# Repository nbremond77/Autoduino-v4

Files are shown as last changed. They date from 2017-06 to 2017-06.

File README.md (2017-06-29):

# Autoduino

Arduino DUE shield to interface the I/O modules of A4 Technology // Autoduino est un bouclier pour Arduino DUE qui permet de piloter les maquettes A4 Technology utilisées pour l'enseignement de la technologie. Il permet également d'interfacer des module Grove.

La face "Bottom":
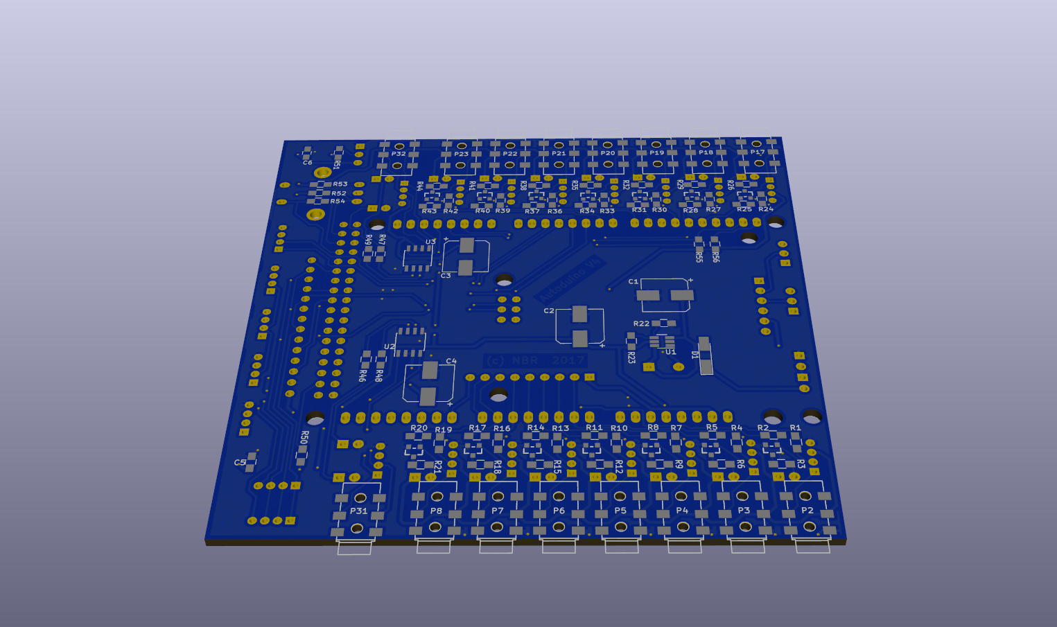
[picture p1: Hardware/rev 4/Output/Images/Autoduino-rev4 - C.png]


La face "Top"
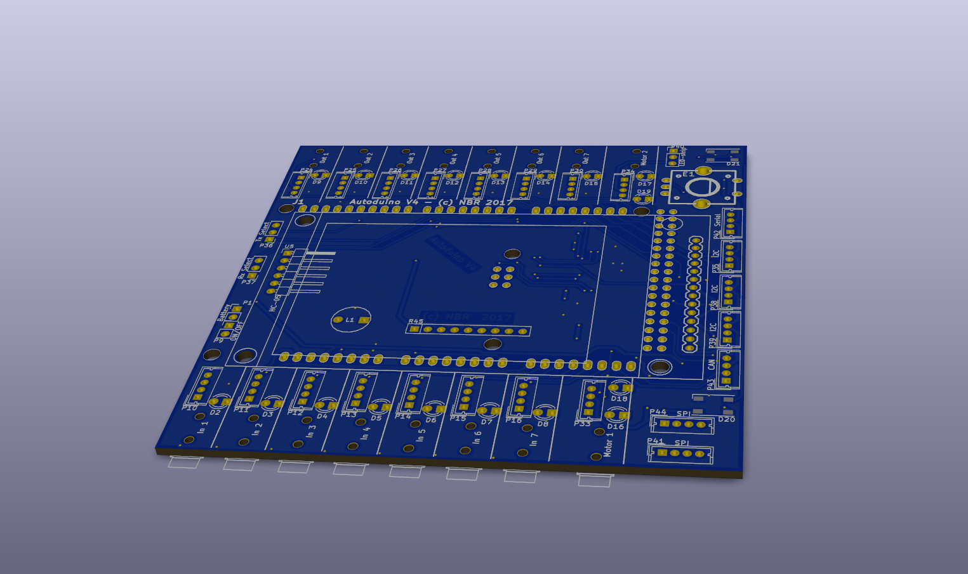
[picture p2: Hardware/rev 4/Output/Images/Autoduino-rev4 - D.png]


Exemples de maquettes A4:

http://www.a4.fr/maquette-motorisee-programmable-portail-1-battant-version-kit.html

http://www.a4.fr/banc-d-essai-eclairage-domestique-autolumi-version-kit.html

http://www.a4.fr/autoalarme-maquette-experimentale-d-un-systeme-d-alarme-kit.html

Vous trouverez sur ce site, les fichiers relatif à la carte électronique, et les développements logiciels associés, dès qu'ils seront disponibles. Cette carte peut être programmée en utilisant l'environnement Arduino. Mais elle peut également en programmée avec Blockly@rDuino, l'excellent projet de Sébastien Canet:

http://technologiescollege.github.io/Blockly-at-rduino/

https://github.com/technologiescollege/Blockly-at-rduino

# Introduction
Le bouclier Autoduino permet de piloter les maquettes A4 technology grâce à un Arduino DUE. Pour cela, le bouclier est équipé de 
- 14 connecteurs Jack 2.5mm permettant la connection des capteurs et actionneurs des maquette A4, équipé de LED pour indiquer l'état de l'entrée ou de la sortie. Des connecteurs Grove (4 broches) sont également prévus, et connectés aux mêmes entrées sorties (voir le schéma pour les détails). Les entrées sont équipées de résistances "Pull-Up" c'est à dire reliées à l'alimentation positive. Les entrées et sorties sont universelles (les schémas sont identiques), les 14 connections peuvent entre utilisées en entrée ou en sortie.
- 2 connecteurs jack 2.5mm pour deux moteurs DC, également complétés par des connecteurs Grove.
- 2 LED RGB adressables (type WS2812B),
- 1 encodeur/push,
- quelques connecteurs supplémentaires permettant de connecter des capteurs/actionneurs plus évolués (I2C, SPI, CAN, Serial...),
- 1 connecteur pour un module BlueTooth,
- 1 convertisseur Step/Up permettant d'alimenter la carte et l'Arduino avec deux piles de 1.5V, ou avec un accumulateur 3.7V,
- 1 connecteur pour un écran graphique couleur tactile de 2.8" connecté en SPI référencé TJCTM24028-SPI disponible pour un prix raisonnable sur Aliexpress.com.

Pour supporter le grand nombre d'entrées/sorties, il a été nécessaire d'utiliser un Arduino plus complet que le UNO. Nous avons choisi le Arduino DUE qui est équipé d'un processeur 32 bits permettant d'héberger des programmes trés complexes.

# Spécificités de l'Arduino DUE

L'Arduino DUE fonctionne en 3.3V, et n'est pas compatible avec des périphériques fonctionnant en 5V. Assurez vous que les périphériques utilisés fonctionnent bien en 3.3V. Les deux interface moteur prévues sur la carte Autoduino sont quant-à-elles alimentées en 5V.

# Schéma électronique

La conception du circuit imprimé a été réalisée avec kiCad, l'excellent logiciel de conception électronique, libre et multiplateforme. Le schéma est disponible ici:
https://github.com/nbremond77/Autoduino-v4/raw/master/Hardware/rev%204/Output/Autoduino-rev4.pdf

# Approvisionnement des composants

Les composants ont été achetés sur Aliepxress, et le PCb a été commandé chez PCBWay.com.

Voici des liens vers les principales références:

La carte Arduino DUE: https://fr.aliexpress.com/item/Free-shipping-Due-R3-ARM-Version-Main-Control-Board-with-usb-cable-for-arduino/32458422375.html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,searchweb201602_2_10152_10065_10151_10068_10305_10304_10306_10136_10137_10060_10302_10155_10062_437_10154_10056_5210020_10055_10054_10059_303_5290020_100031_10099_10103_10102_10096_10052_10053_10050_10107_10142_10051_5280011_10084_10083_10080_10082_10081_5260020_5270020_10177_5320020_10110_519_10111_10112_10113_10114_10182_10184_10078_10079_5240020_5230020_10073_10123_5250020_10189_142,searchweb201603_49,ppcSwitch_5&btsid=a1133e54-5694-44cb-906c-6a8b10082eb8&algo_expid=972c692f-a693-491d-9626-1f7036225856-1&algo_pvid=972c692f-a693-491d-9626-1f7036225856

Les connecteurs Jack 2.5mm CMS ref. PJ-242 : https://fr.aliexpress.com/item/500pcs-lot-PJ-242-6P-SMT-2-5MM-Female-Audio-Headphone-Jack-2-5MM-Dual-Track/32344264172.html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

L'écran LCD couleur tactile de 2.8" (attention, certains modèle ne sont pas équipés de l'interface tactile) : https://fr.aliexpress.com/item/2-8-Inch-240x320-Serial-Port-SPI-TFT-Screen-LCD-with-Touch-Screen-Panel-PCB-Board/32617643223.html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

Le module BlueTooth HC05 (les broches devront peut-être être déssoudées et remplacées par des barettes droites soudées sur la face inférieure) : https://fr.aliexpress.com/item/HC05-HC-05-master-slave-6pin-JY-MCU-anti-reverse-integrated-Bluetooth-serial-pass-through-module/32788718239.html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,searchweb201602_2_10152_10065_10151_10068_10305_10304_10306_10136_10137_10060_10302_10155_10062_437_10154_10056_5210020_10055_10054_10059_303_5290020_100031_10099_10103_10102_10096_10052_10053_10050_10107_10142_10051_5280011_10084_10083_10080_10082_10081_5260020_5270020_10177_5320020_10110_519_10111_10112_10113_10114_10182_10184_10078_10079_5240020_5230020_10073_10123_5250020_10189_142-10050,searchweb201603_49,ppcSwitch_5&btsid=7052be95-a9a1-4971-bb41-739faffda7ad&algo_expid=dd608b64-cccf-44a9-9c7e-1e9cdb78854b-7&algo_pvid=dd608b64-cccf-44a9-9c7e-1e9cdb78854b

Les autres composants sont des modèles standards.

# Circuit imprimé et fabrication

Autoduino utilise des composants CMS et des composants traversants. Le cuircuit imprimé fait 100x100mm et est du type double-face à trous métalisés. Nous l'avons fait fariqué chez PCBWay.com à un prix trés compétitif. Tous les fichiers nécessaires à sa fabrication sont dans le répertoire Output/Manufacturing (voir le fichier .Zip dans ce répertoire). Pensez également à commander un "Stencyl" pour la face "Bottom". Le Stencyl est un feuille de métal performée au laser au niveau des pastilles de soudure, et qui permet de grandement faciliter l'application de la pate à braser utilisée pour souder les  composants CMS.

Pour l'assemblage, de nombreux composants sont "montés en surface (CMS) sur la face "Bottom". Nous avons utilisé le Stencyl pour appliquer la pate à braser, positionné les composants CMS sur la carte, et passé la carte aisni équipé dans un four à refusion fait "maison" (plusieurs projets sont disponibles sur le web...).
Le montage des composants traversants, et des 2 LED sur la face "Top" se fait manuellement, aprés la refusion et le refroidissement de la carte. Cette méthode permet de réaliser plusieurs exemplaires de la carte en un temps raisonnable.

# Programmation
La programmation de l'Arduino peut se faire grâce à blockly@rDuino: http://technologiescollege.github.io/ en utilisant les blocs Grove par exemple.

http://technologiescollege.github.io/Blockly-at-rduino/

https://github.com/technologiescollege/Blockly-at-rduino

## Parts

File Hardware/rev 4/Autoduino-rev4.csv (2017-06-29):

Reference | Value | Footprint | Datasheet
U1 | MCP1640t-i/chy | TO_SOT_Packages_SMD:SOT-23-6_Handsoldering
C2 | 220uF/16V | Capacitors_SMD:CP_Elec_8x10
C1 | 220uF/16V | Capacitors_SMD:CP_Elec_8x10
R23 | 976k 1% | Resistors_SMD:R_0805_HandSoldering
R22 | 309k 1% | Resistors_SMD:R_0805_HandSoldering
L1 | 4.7uH | Inductors:INDUCTOR_V
E1 | Encoder_switch | BR_GoodLibraries:encoder_alps-ec12d
C6 | 100n | Capacitors_SMD:C_0805_HandSoldering
D20 | WS2812B | LEDs:LED_WS2812B-PLCC4
D21 | WS2812B | LEDs:LED_WS2812B-PLCC4
U5 | HC-05 | Pin_Headers:Pin_Header_Angled_1x06_Pitch2.54mm
C3 | 220uF/16V | Capacitors_SMD:CP_Elec_8x10
R51 | 220R | Resistors_SMD:R_0805_HandSoldering
P40 | LED-strip | Pin_Headers:Pin_Header_Straight_1x03_Pitch2.54mm
R46 | 470R | Resistors_SMD:R_0805_HandSoldering
R48 | 470R | Resistors_SMD:R_0805_HandSoldering
D16 | LED | LEDs:LED_D3.0mm
D18 | LED | LEDs:LED_D3.0mm
D2 | LED | LEDs:LED_D3.0mm
R3 | 470R | Resistors_SMD:R_0805_HandSoldering
Q1 | BSS138 | BR_GoodLibraries:SOT23_FET
R2 | 220R | Resistors_SMD:R_0805_HandSoldering
P10 | In_Out | Connectors_Molex:Molex_MicroLatch-53253-0470_04x2.00mm_Straight
R1 | 220R | Resistors_SMD:R_0805_HandSoldering
D3 | LED | LEDs:LED_D3.0mm
R6 | 470R | Resistors_SMD:R_0805_HandSoldering
Q2 | BSS138 | BR_GoodLibraries:SOT23_FET
R5 | 220R | Resistors_SMD:R_0805_HandSoldering
P11 | In_Out | Connectors_Molex:Molex_MicroLatch-53253-0470_04x2.00mm_Straight
R4 | 220R | Resistors_SMD:R_0805_HandSoldering
D4 | LED | LEDs:LED_D3.0mm
R9 | 470R | Resistors_SMD:R_0805_HandSoldering
Q3 | BSS138 | BR_GoodLibraries:SOT23_FET
R8 | 220R | Resistors_SMD:R_0805_HandSoldering
P12 | In_Out | Connectors_Molex:Molex_MicroLatch-53253-0470_04x2.00mm_Straight
R7 | 220R | Resistors_SMD:R_0805_HandSoldering
D5 | LED | LEDs:LED_D3.0mm
R12 | 470R | Resistors_SMD:R_0805_HandSoldering
Q4 | BSS138 | BR_GoodLibraries:SOT23_FET
R11 | 220R | Resistors_SMD:R_0805_HandSoldering
P13 | In_Out | Connectors_Molex:Molex_MicroLatch-53253-0470_04x2.00mm_Straight
R10 | 220R | Resistors_SMD:R_0805_HandSoldering
D6 | LED | LEDs:LED_D3.0mm
R15 | 470R | Resistors_SMD:R_0805_HandSoldering
Q5 | BSS138 | BR_GoodLibraries:SOT23_FET
R14 | 220R | Resistors_SMD:R_0805_HandSoldering
P14 | In_Out | Connectors_Molex:Molex_MicroLatch-53253-0470_04x2.00mm_Straight
R13 | 220R | Resistors_SMD:R_0805_HandSoldering
D9 | LED | LEDs:LED_D3.0mm
R26 | 470R | Resistors_SMD:R_0805_HandSoldering
Q8 | BSS138 | BR_GoodLibraries:SOT23_FET
R25 | 220R | Resistors_SMD:R_0805_HandSoldering
P24 | In_Out | Connectors_Molex:Molex_MicroLatch-53253-0470_04x2.00mm_Straight
R24 | 220R | Resistors_SMD:R_0805_HandSoldering
D10 | LED | LEDs:LED_D3.0mm
R29 | 470R | Resistors_SMD:R_0805_HandSoldering
Q9 | BSS138 | BR_GoodLibraries:SOT23_FET
R28 | 220R | Resistors_SMD:R_0805_HandSoldering
P25 | In_Out | Connectors_Molex:Molex_MicroLatch-53253-0470_04x2.00mm_Straight
R27 | 220R | Resistors_SMD:R_0805_HandSoldering
D11 | LED | LEDs:LED_D3.0mm
R32 | 470R | Resistors_SMD:R_0805_HandSoldering
Q10 | BSS138 | BR_GoodLibraries:SOT23_FET
R31 | 220R | Resistors_SMD:R_0805_HandSoldering
P26 | In_Out | Connectors_Molex:Molex_MicroLatch-53253-0470_04x2.00mm_Straight
R30 | 220R | Resistors_SMD:R_0805_HandSoldering
D12 | LED | LEDs:LED_D3.0mm
R35 | 470R | Resistors_SMD:R_0805_HandSoldering
Q11 | BSS138 | BR_GoodLibraries:SOT23_FET
R34 | 220R | Resistors_SMD:R_0805_HandSoldering
P27 | In_Out | Connectors_Molex:Molex_MicroLatch-53253-0470_04x2.00mm_Straight
R33 | 220R | Resistors_SMD:R_0805_HandSoldering
D13 | LED | LEDs:LED_D3.0mm
R38 | 470R | Resistors_SMD:R_0805_HandSoldering
Q12 | BSS138 | BR_GoodLibraries:SOT23_FET
R37 | 220R | Resistors_SMD:R_0805_HandSoldering
P28 | In_Out | Connectors_Molex:Molex_MicroLatch-53253-0470_04x2.00mm_Straight
R36 | 220R | Resistors_SMD:R_0805_HandSoldering
D7 | LED | LEDs:LED_D3.0mm
R18 | 470R | Resistors_SMD:R_0805_HandSoldering
Q6 | BSS138 | BR_GoodLibraries:SOT23_FET
R17 | 220R | Resistors_SMD:R_0805_HandSoldering
P15 | In_Out | Connectors_Molex:Molex_MicroLatch-53253-0470_04x2.00mm_Straight
R16 | 220R | Resistors_SMD:R_0805_HandSoldering
D14 | LED | LEDs:LED_D3.0mm
R41 | 470R | Resistors_SMD:R_0805_HandSoldering
Q13 | BSS138 | BR_GoodLibraries:SOT23_FET
R40 | 220R | Resistors_SMD:R_0805_HandSoldering
P29 | In_Out | Connectors_Molex:Molex_MicroLatch-53253-0470_04x2.00mm_Straight
R39 | 220R | Resistors_SMD:R_0805_HandSoldering
P33 | Motor 1 | Connectors_Molex:Molex_MicroLatch-53253-0470_04x2.00mm_Straight
U4 | ILI9341_LCD_Breakout_with_TS_IRQ | BR_GoodLibraries:LCD_2.8_Touch_screen
R45 | R-SIL 2K | Resistors_THT:R_Array_SIP9
R50 | 220R | Resistors_SMD:R_0805_HandSoldering
J1 | Arduino_Due_Header | BR_GoodLibraries:ARDUINO_MEGA_SHIELD
P1 | Battery | Pin_Headers:Pin_Header_Straight_1x02_Pitch2.54mm
U2 | L9110 | Housings_SOIC:SOIC-8_3.9x4.9mm_Pitch1.27mm
C4 | 220uF/16V | Capacitors_SMD:CP_Elec_8x10
R47 | 470R | Resistors_SMD:R_0805_HandSoldering
R49 | 470R | Resistors_SMD:R_0805_HandSoldering
D17 | LED | LEDs:LED_D3.0mm
D19 | LED | LEDs:LED_D3.0mm
P34 | Motor 2 | Connectors_Molex:Molex_MicroLatch-53253-0470_04x2.00mm_Straight
U3 | L9110 | Housings_SOIC:SOIC-8_3.9x4.9mm_Pitch1.27mm
P9 | ON/OFF Switch | Pin_Headers:Pin_Header_Straight_1x02_Pitch2.54mm
P36 | Tx Select | Pin_Headers:Pin_Header_Straight_1x03_Pitch2.54mm
P37 | Rx Select | Pin_Headers:Pin_Header_Straight_1x03_Pitch2.54mm
P31 | MOTOR1 | BR_GoodLibraries:3.5mm_stereo_jack_PJ242_NBR
P32 | MOTOR2 | BR_GoodLibraries:3.5mm_stereo_jack_PJ242_NBR
P7 | IN_OUT | BR_GoodLibraries:3.5mm_stereo_jack_PJ242_NBR
P6 | IN_OUT | BR_GoodLibraries:3.5mm_stereo_jack_PJ242_NBR
P5 | IN_OUT | BR_GoodLibraries:3.5mm_stereo_jack_PJ242_NBR
P4 | IN_OUT | BR_GoodLibraries:3.5mm_stereo_jack_PJ242_NBR
P3 | IN_OUT | BR_GoodLibraries:3.5mm_stereo_jack_PJ242_NBR
P2 | IN_OUT | BR_GoodLibraries:3.5mm_stereo_jack_PJ242_NBR
P17 | IN_OUT | BR_GoodLibraries:3.5mm_stereo_jack_PJ242_NBR
P18 | IN_OUT | BR_GoodLibraries:3.5mm_stereo_jack_PJ242_NBR
P19 | IN_OUT | BR_GoodLibraries:3.5mm_stereo_jack_PJ242_NBR
P20 | IN_OUT | BR_GoodLibraries:3.5mm_stereo_jack_PJ242_NBR
P21 | IN_OUT | BR_GoodLibraries:3.5mm_stereo_jack_PJ242_NBR
P22 | IN_OUT | BR_GoodLibraries:3.5mm_stereo_jack_PJ242_NBR
D8 | LED | LEDs:LED_D3.0mm
R21 | 470R | Resistors_SMD:R_0805_HandSoldering
Q7 | BSS138 | BR_GoodLibraries:SOT23_FET
R20 | 220R | Resistors_SMD:R_0805_HandSoldering
P16 | In_Out | Connectors_Molex:Molex_MicroLatch-53253-0470_04x2.00mm_Straight
R19 | 220R | Resistors_SMD:R_0805_HandSoldering
D15 | LED | LEDs:LED_D3.0mm
R44 | 470R | Resistors_SMD:R_0805_HandSoldering
Q14 | BSS138 | BR_GoodLibraries:SOT23_FET
R43 | 220R | Resistors_SMD:R_0805_HandSoldering
P30 | In_Out | Connectors_Molex:Molex_MicroLatch-53253-0470_04x2.00mm_Straight
R42 | 220R | Resistors_SMD:R_0805_HandSoldering
P8 | IN_OUT | BR_GoodLibraries:3.5mm_stereo_jack_PJ242_NBR
P23 | IN_OUT | BR_GoodLibraries:3.5mm_stereo_jack_PJ242_NBR
C5 | 100n | Capacitors_SMD:C_0805_HandSoldering
P35 | I2C | Connectors_Molex:Molex_MicroLatch-53253-0470_04x2.00mm_Straight
P38 | I2C | Connectors_Molex:Molex_MicroLatch-53253-0470_04x2.00mm_Straight
P39 | I2C | Connectors_Molex:Molex_MicroLatch-53253-0470_04x2.00mm_Straight
P41 | SPI | Connectors_Molex:Molex_MicroLatch-53253-0470_04x2.00mm_Straight
D1 | DIODE_SCHOTTKY | Diodes_SMD:D_MiniMELF_Handsoldering
P44 | SPI | Connectors_Molex:Molex_MicroLatch-53253-0470_04x2.00mm_Straight
P42 | Serial | Connectors_Molex:Molex_MicroLatch-53253-0470_04x2.00mm_Straight
R54 | 10k | Resistors_SMD:R_0805_HandSoldering
R53 | 10k | Resistors_SMD:R_0805_HandSoldering
R52 | 10k | Resistors_SMD:R_0805_HandSoldering
P43 | CAN | Connectors_Molex:Molex_MicroLatch-53253-0470_04x2.00mm_Straight
R55 | 10k | Resistors_SMD:R_0805_HandSoldering
R56 | 10k | Resistors_SMD:R_0805_HandSoldering

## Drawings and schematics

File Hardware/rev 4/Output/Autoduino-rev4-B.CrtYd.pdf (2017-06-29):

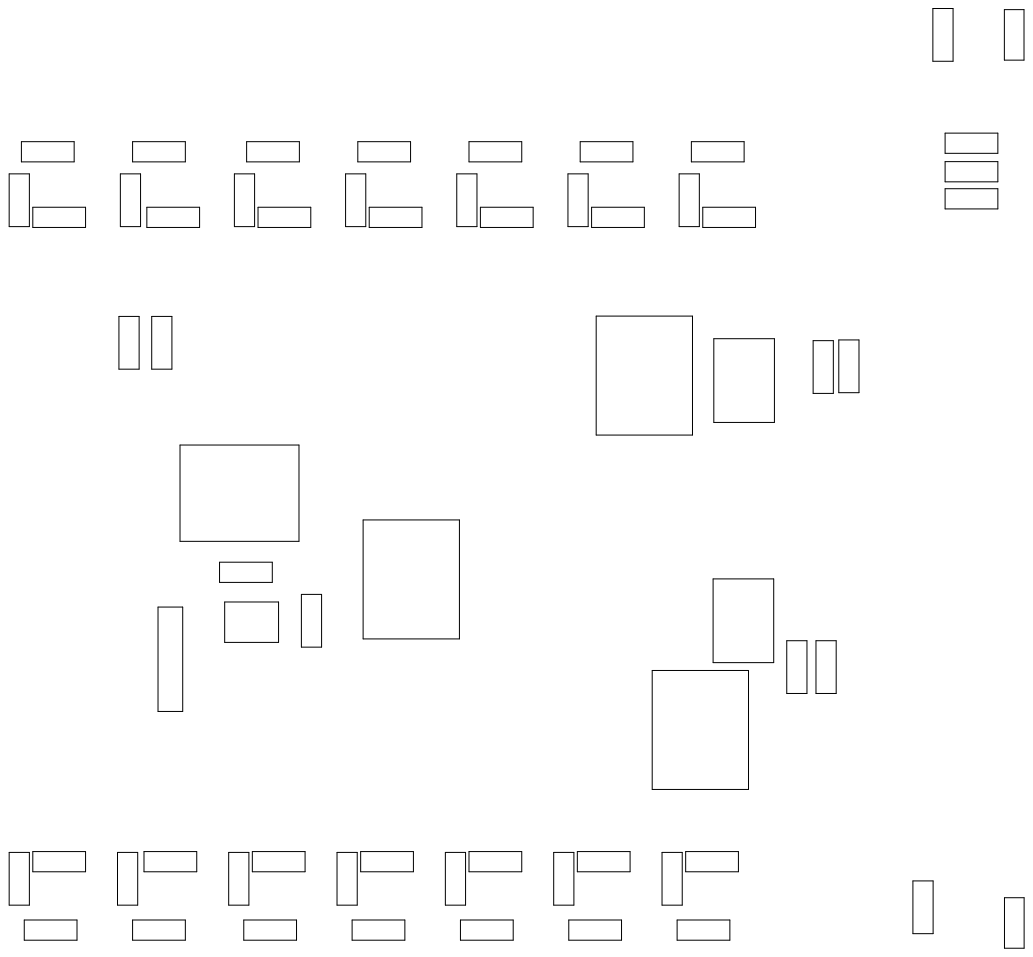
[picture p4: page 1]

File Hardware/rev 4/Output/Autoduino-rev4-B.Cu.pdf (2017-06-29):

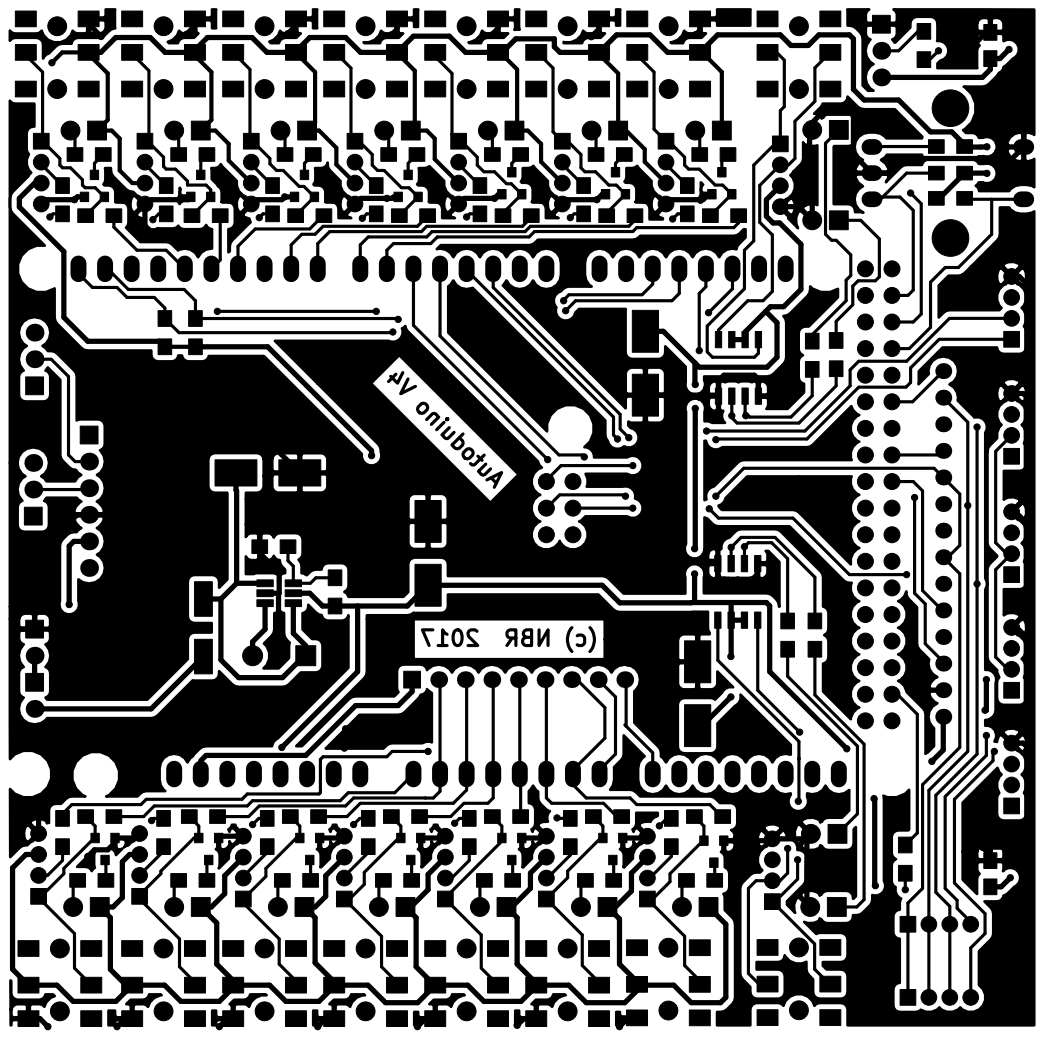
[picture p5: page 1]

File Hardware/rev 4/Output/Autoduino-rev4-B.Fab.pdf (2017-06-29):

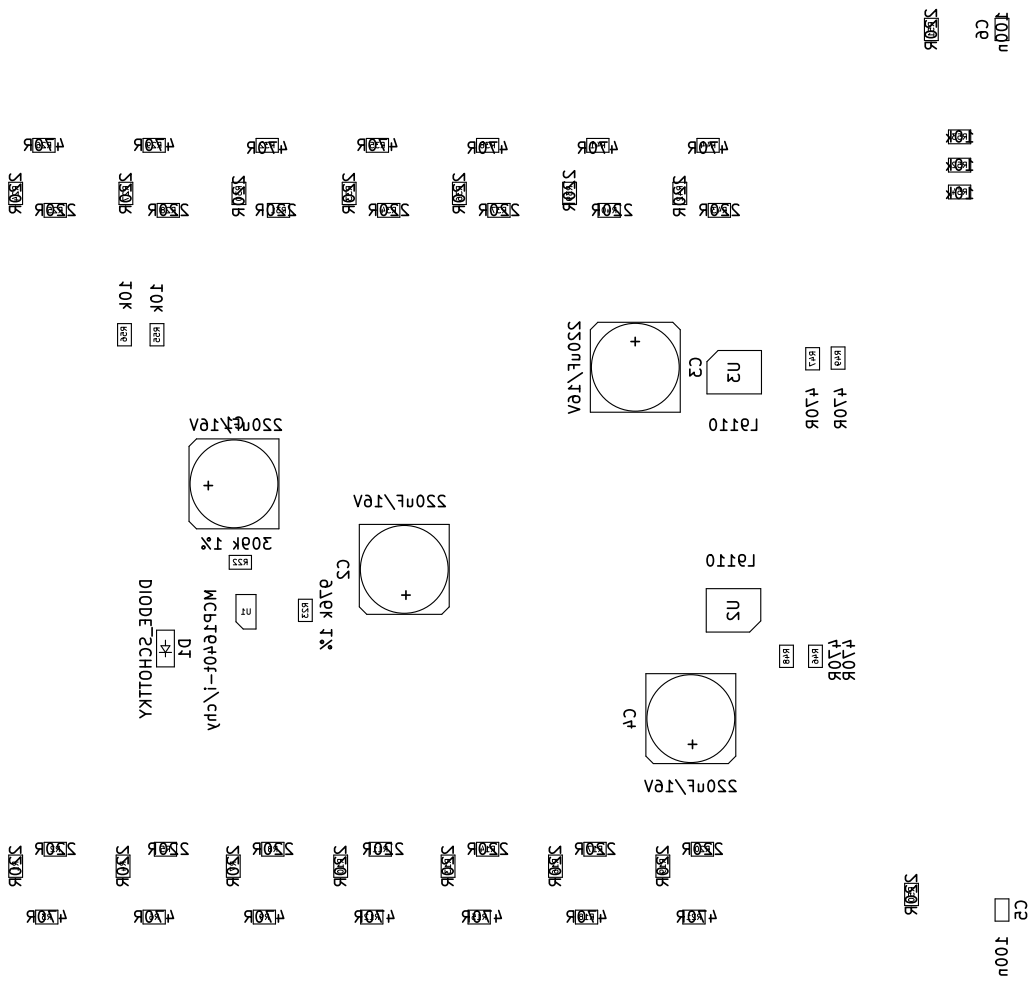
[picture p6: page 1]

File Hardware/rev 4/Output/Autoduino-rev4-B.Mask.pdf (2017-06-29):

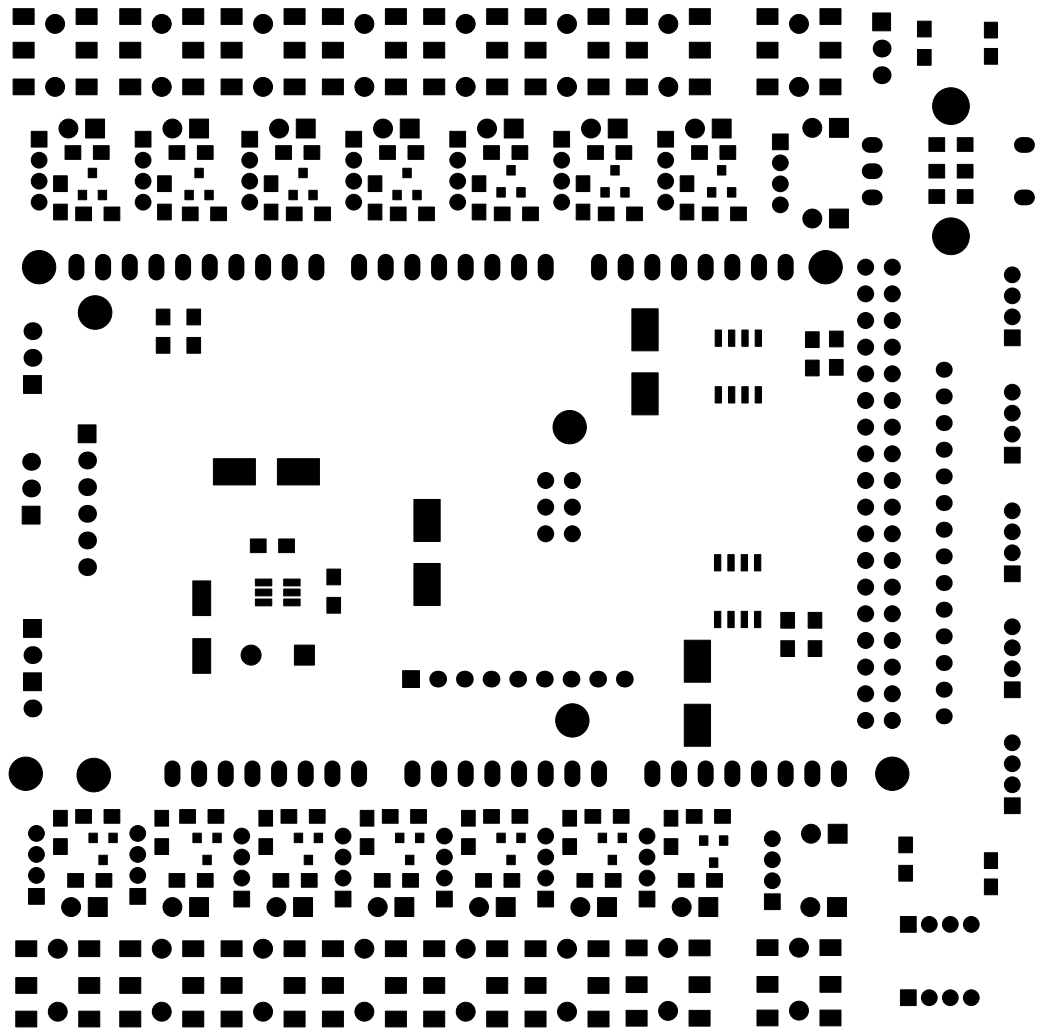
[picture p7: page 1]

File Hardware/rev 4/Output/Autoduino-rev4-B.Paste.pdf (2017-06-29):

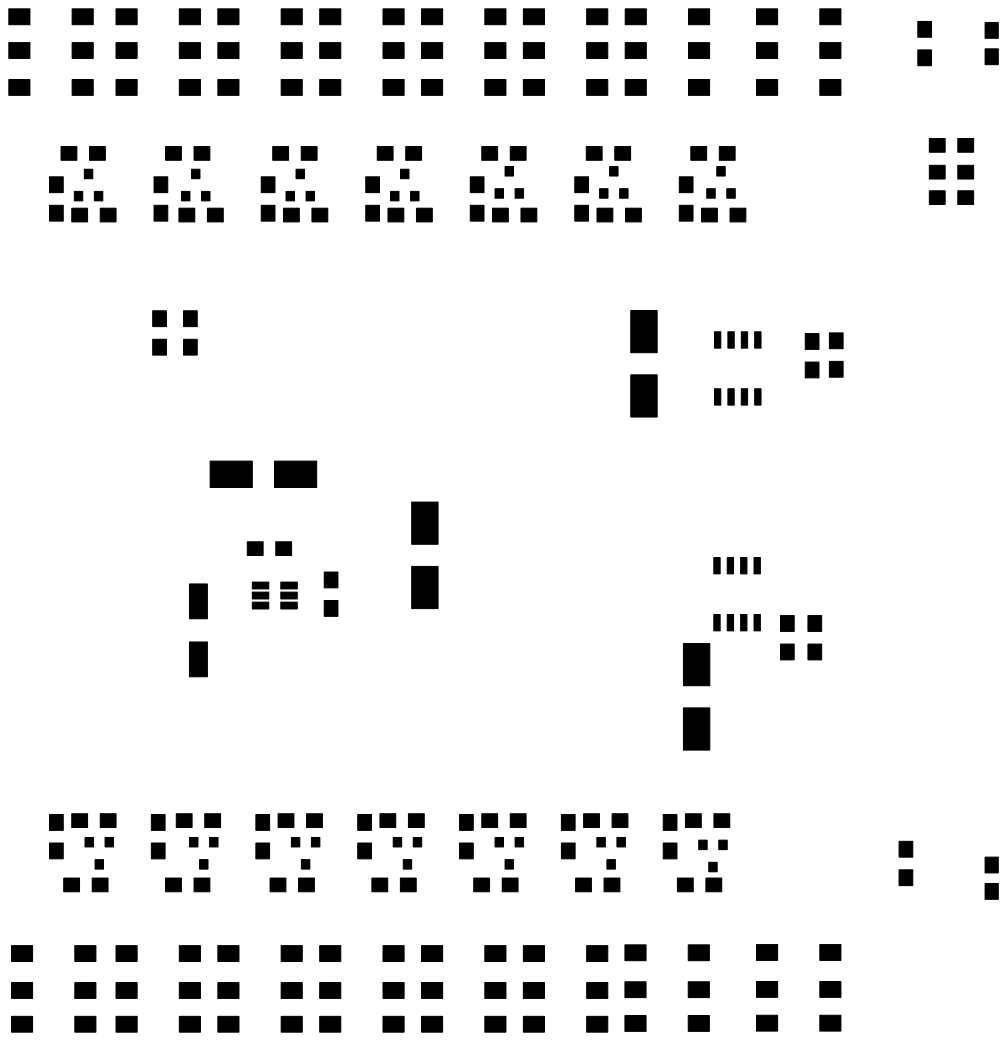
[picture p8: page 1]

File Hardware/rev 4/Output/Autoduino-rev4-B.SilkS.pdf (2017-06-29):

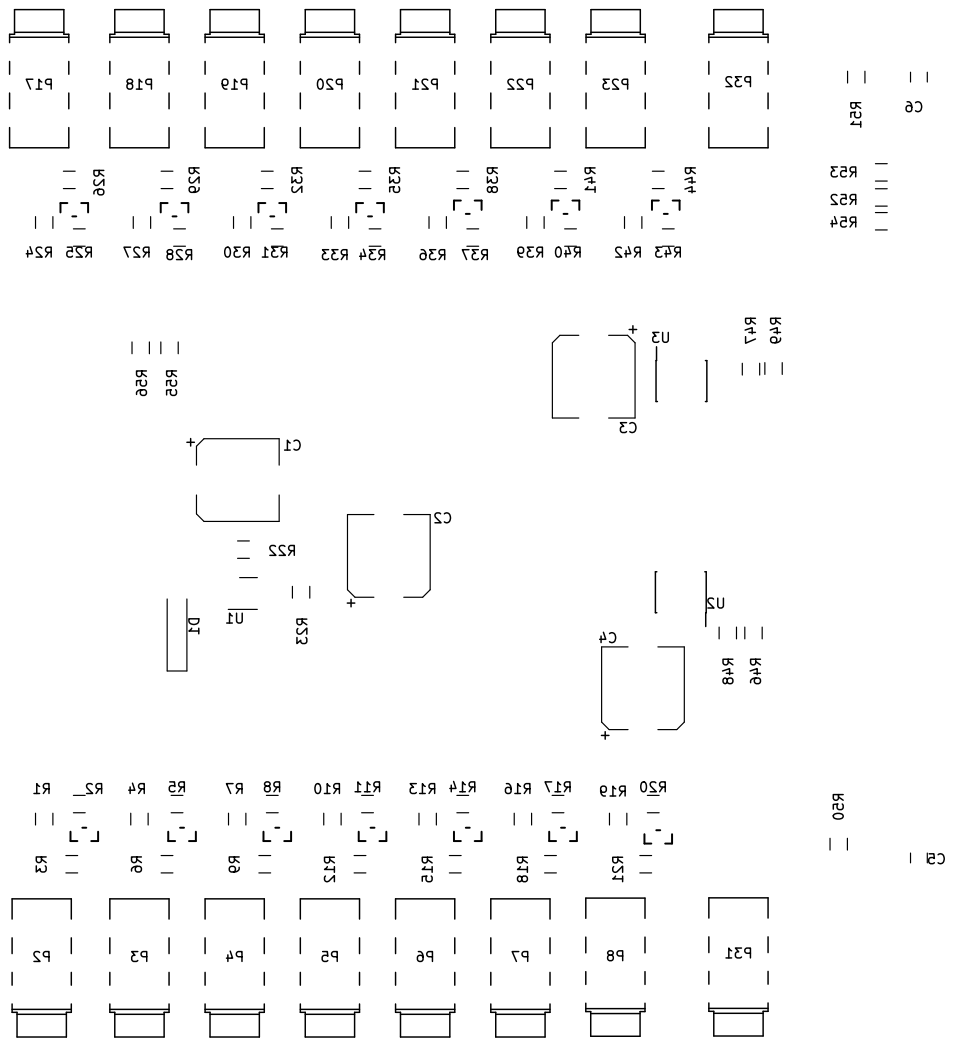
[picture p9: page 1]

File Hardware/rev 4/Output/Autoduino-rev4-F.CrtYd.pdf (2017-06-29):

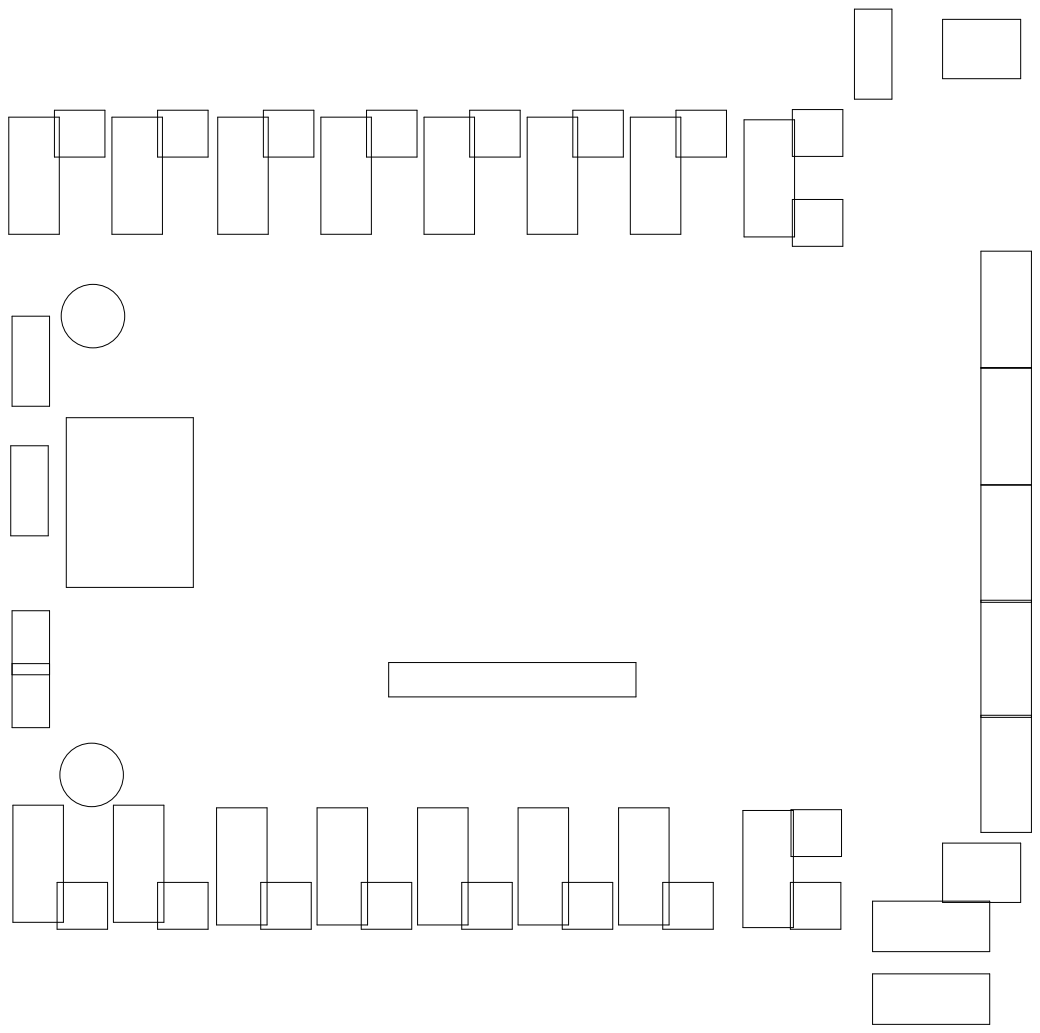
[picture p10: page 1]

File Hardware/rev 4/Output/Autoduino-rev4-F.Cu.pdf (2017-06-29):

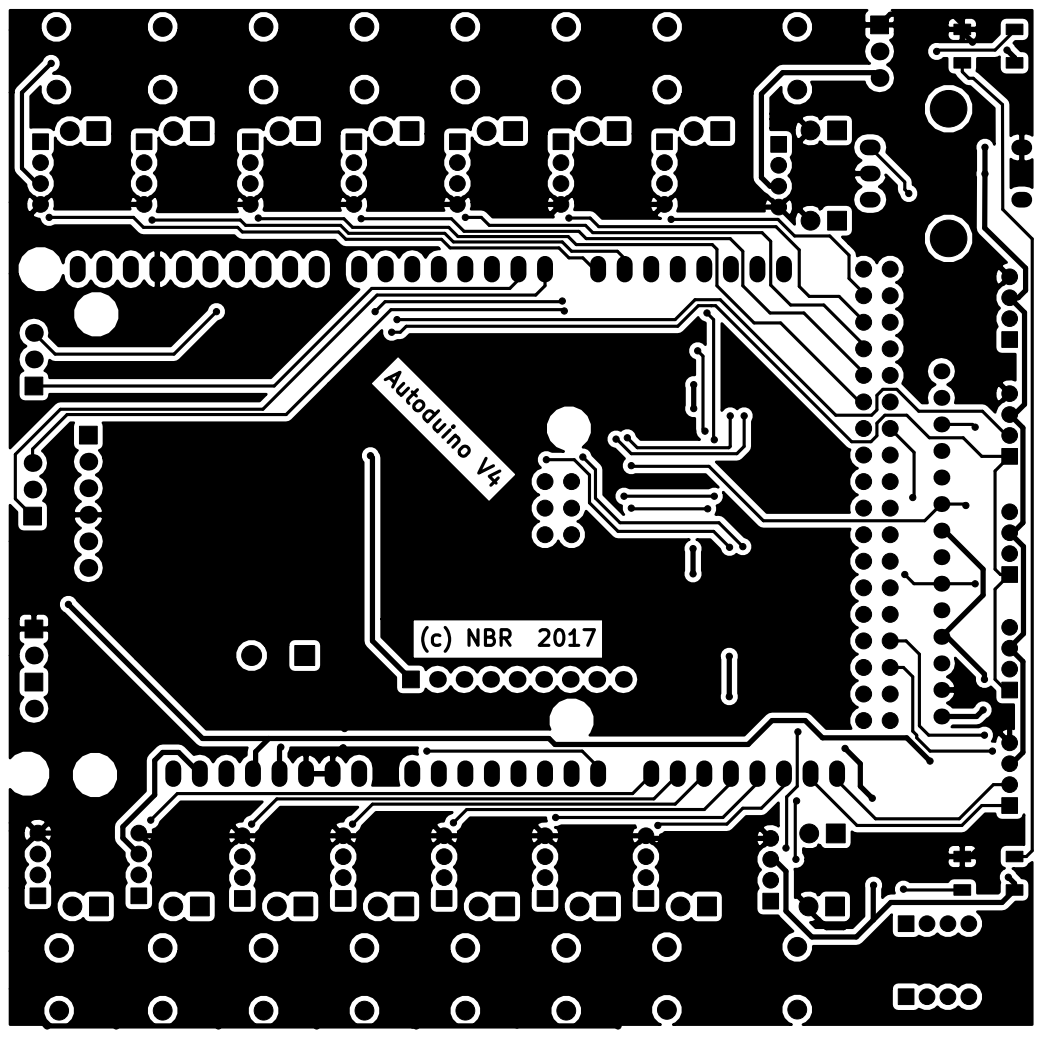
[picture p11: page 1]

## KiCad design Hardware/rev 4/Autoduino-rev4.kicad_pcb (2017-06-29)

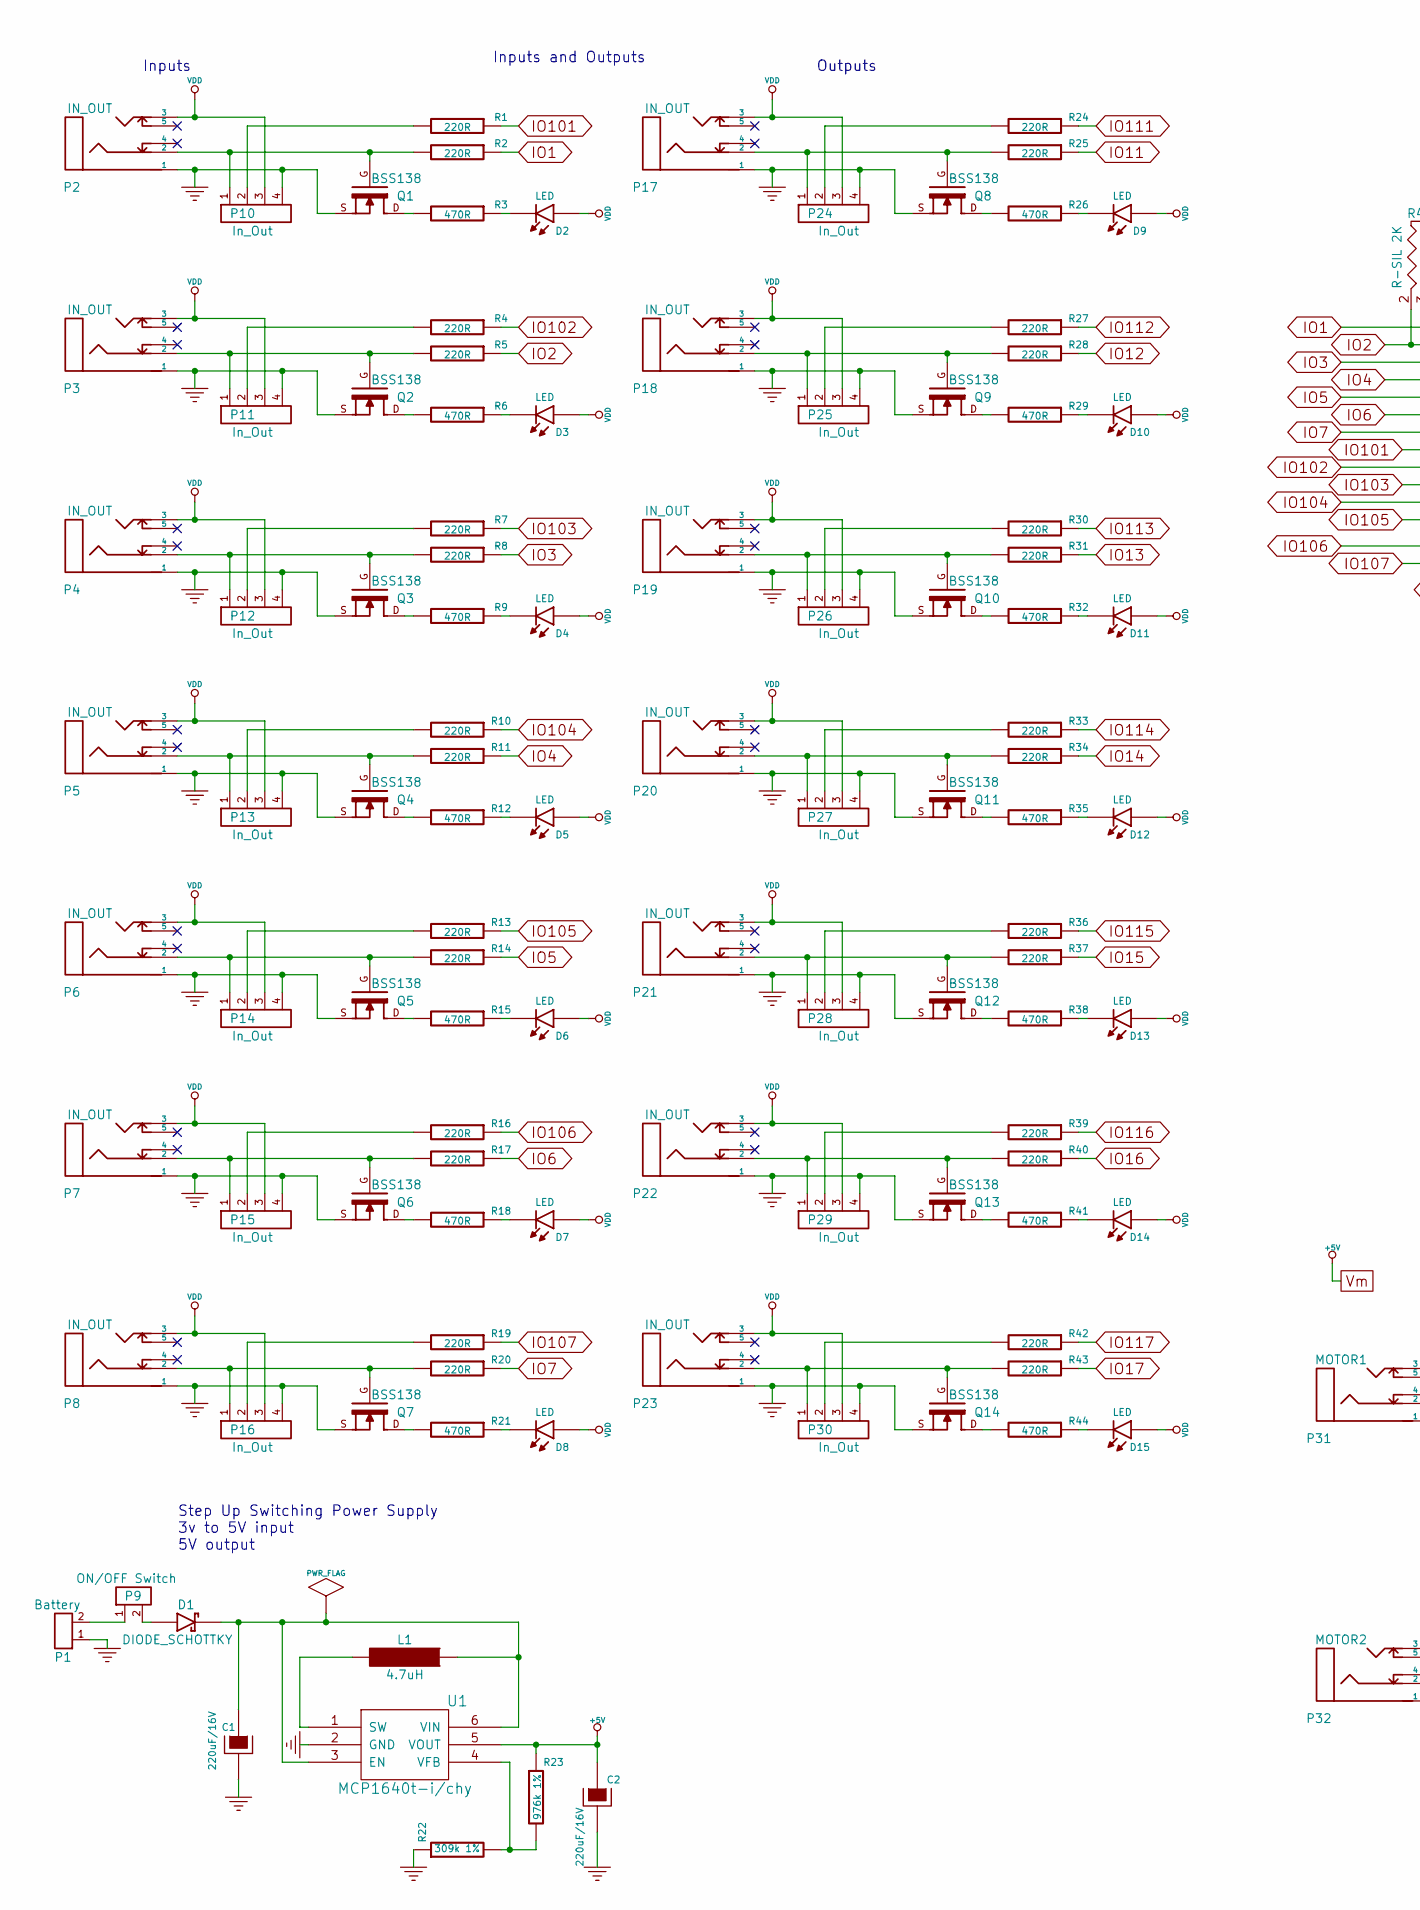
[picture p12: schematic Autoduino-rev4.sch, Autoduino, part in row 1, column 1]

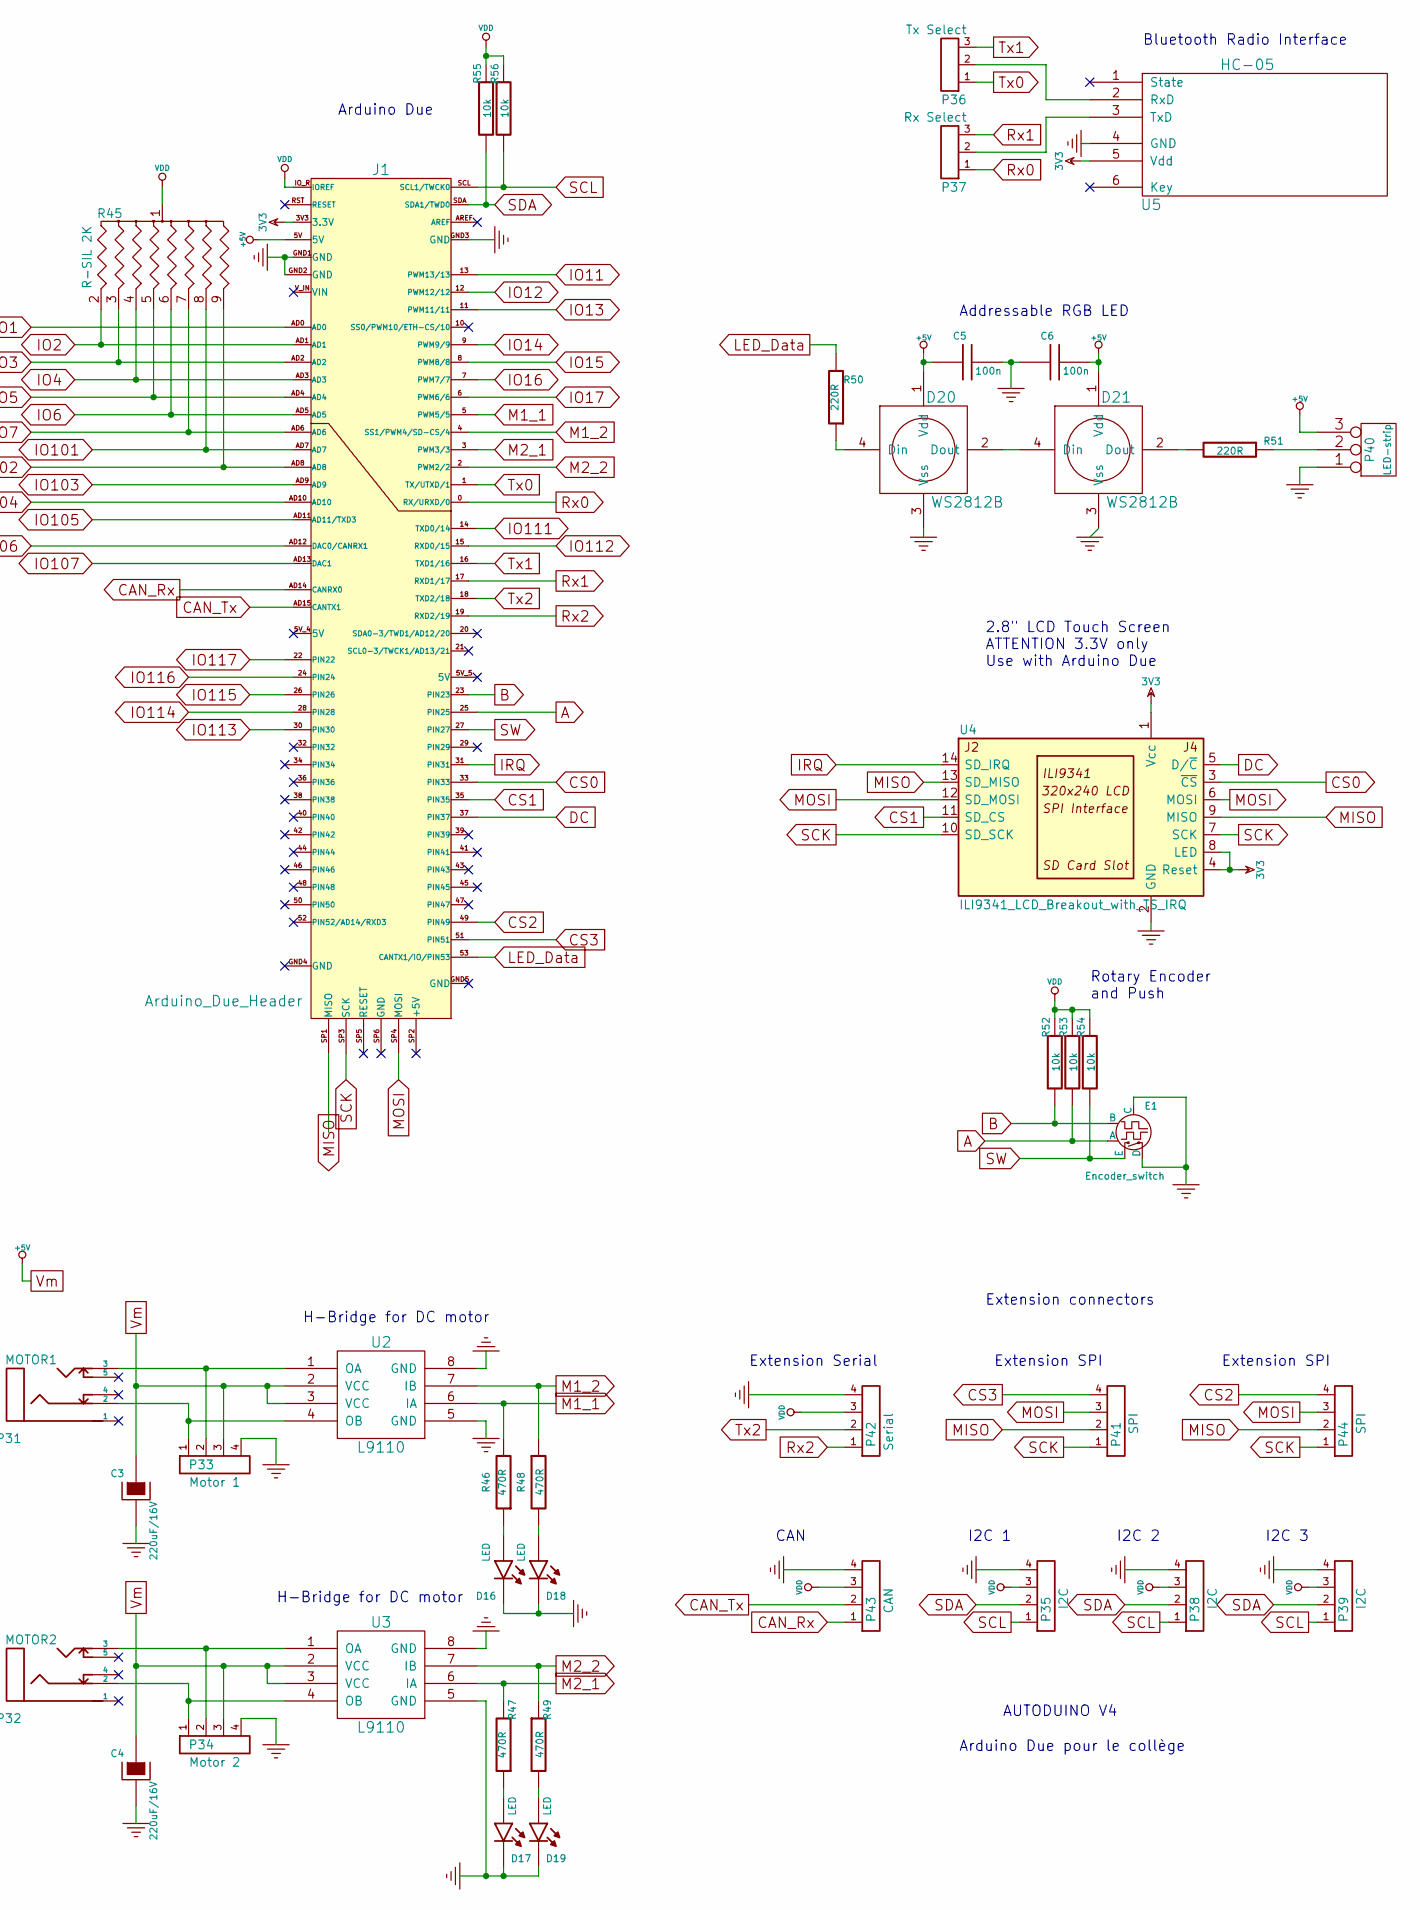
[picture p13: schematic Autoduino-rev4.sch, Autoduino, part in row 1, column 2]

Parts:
C1, C2, C3, C4: 220uF/16V; CP_Elec_8x10
C5, C6: 100n; C_0805_HandSoldering
D1: DIODE_SCHOTTKY; D_MiniMELF_Handsoldering
D2, D3, D4, D5, D6, D7, D8, D9, D10, D11, D12, D13, D14, D15, D16, D17, D18, D19: LED; LED_D3.0mm
D20, D21: WS2812B; LED_WS2812B-PLCC4
E1: Encoder_switch; encoder_alps-ec12d
J1: Arduino_Due_Header; ARDUINO_MEGA_SHIELD
L1: 4.7uH; INDUCTOR_V
P1: Battery; Pin_Header_Straight_1x02_Pitch2.54mm
P2, P3, P4, P5, P6, P7, P8, P17, P18, P19, P20, P21, P22, P23: IN_OUT; 3.5mm_stereo_jack_PJ242_NBR
P9: ON/OFF Switch; Pin_Header_Straight_1x02_Pitch2.54mm
P10, P11, P12, P13, P14, P15, P16, P24, P25, P26, P27, P28, P29, P30: In_Out; Molex_MicroLatch-53253-0470_04x2.00mm_Straight
P31: MOTOR1; 3.5mm_stereo_jack_PJ242_NBR
P32: MOTOR2; 3.5mm_stereo_jack_PJ242_NBR
P33: Motor 1; Molex_MicroLatch-53253-0470_04x2.00mm_Straight
P34: Motor 2; Molex_MicroLatch-53253-0470_04x2.00mm_Straight
P35, P38, P39: I2C; Molex_MicroLatch-53253-0470_04x2.00mm_Straight
P36: Tx Select; Pin_Header_Straight_1x03_Pitch2.54mm
P37: Rx Select; Pin_Header_Straight_1x03_Pitch2.54mm
P40: LED-strip; Pin_Header_Straight_1x03_Pitch2.54mm
P41, P44: SPI; Molex_MicroLatch-53253-0470_04x2.00mm_Straight
P42: Serial; Molex_MicroLatch-53253-0470_04x2.00mm_Straight
P43: CAN; Molex_MicroLatch-53253-0470_04x2.00mm_Straight
Q1, Q2, Q3, Q4, Q5, Q6, Q7, Q8, Q9, Q10, Q11, Q12, Q13, Q14: BSS138; SOT23_FET
R1, R2, R4, R5, R7, R8, R10, R11, R13, R14, R16, R17, R19, R20, R24, R25, R27, R28, R30, R31, R33, R34, R36, R37, R39, R40, R42, R43, R50, R51: 220R; R_0805_HandSoldering
R3, R6, R9, R12, R15, R18, R21, R26, R29, R32, R35, R38, R41, R44, R46, R47, R48, R49: 470R; R_0805_HandSoldering
R22: 309k 1%; R_0805_HandSoldering
R23: 976k 1%; R_0805_HandSoldering
R45: R-SIL 2K; R_Array_SIP9
R52, R53, R54, R55, R56: 10k; R_0805_HandSoldering
U1: MCP1640t-i/chy; SOT-23-6_Handsoldering
U2, U3: L9110; SOIC-8_3.9x4.9mm_Pitch1.27mm
U4: ILI9341_LCD_Breakout_with_TS_IRQ; LCD_2.8_Touch_screen
U5: HC-05; Pin_Header_Angled_1x06_Pitch2.54mm

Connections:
3V3: J1.3V3 (3.3V), U4.1 (Vcc), U4.4 (Reset), U4.8 (LED), U5.5 (Vdd)
A: E1.1 (A), J1.25 (PIN25), R53.2
B: E1.3 (B), J1.23 (PIN23), R52.2
CAN_Rx: J1.AD14 (CANRX0), P43.1
CAN_Tx: J1.AD15 (CANTX1), P43.2
CS0: J1.33 (PIN33), U4.3 (~CS)
CS1: J1.35 (PIN35), U4.11 (SD_CS)
CS2: J1.49 (PIN49), P44.4
CS3: J1.51 (PIN51), P41.4
DC: J1.37 (PIN37), U4.5 (D/~C)
GND: C1.2, C2.2, C3.2, C4.2, C5.2, C6.1, D16.2 (K), D17.2 (K), D18.2 (K), D19.2 (K), D20.3 (Vss), D21.3 (Vss), E1.2 (C), E1.5 (D), J1.GND1 (GND), J1.GND2 (GND), J1.GND3 (GND), P1.1, P2.1, P3.1, P4.1, P5.1, P6.1, P7.1, P8.1, P10.4, P11.4, P12.4, P13.4, P14.4, P15.4, P16.4, P17.1, P18.1, P19.1, P20.1, P21.1, P22.1, P23.1, P24.4, P25.4, P26.4, P27.4, P28.4, P29.4, P30.4, P33.4, P34.4, P35.4, P38.4, P39.4, P40.1, P42.4, P43.4, Q1.S, Q2.S, Q3.S, Q4.S, Q5.S, Q6.S, Q7.S, Q8.S, Q9.S, Q10.S, Q11.S, Q12.S, Q13.S, Q14.S, R22.1, U1.2 (GND), U2.5 (GND), U2.8 (GND), U3.5 (GND), U3.8 (GND), U4.2 (GND), U5.4 (GND)
IO1: J1.AD0, R2.1
IO2: J1.AD1, R5.1, R45.2
IO3: J1.AD2, R8.1, R45.3
IO4: J1.AD3, R11.1, R45.4
IO5: J1.AD4, R14.1, R45.5
IO6: J1.AD5, R17.1, R45.6
IO7: J1.AD6, R20.1, R45.7
IO11: J1.13 (PWM13/13), R25.1
IO12: J1.12 (PWM12/12), R28.1
IO13: J1.11 (PWM11/11), R31.1
IO14: J1.9 (PWM9/9), R34.1
IO15: J1.8 (PWM8/8), R37.1
IO16: J1.7 (PWM7/7), R40.1
IO17: J1.6 (PWM6/6), R43.1
IO101: J1.AD7, R1.1, R45.8
IO102: J1.AD8, R4.1, R45.9
IO103: J1.AD9, R7.1
IO104: J1.AD10, R10.1
IO105: J1.AD11 (AD11/TXD3), R13.1
IO106: J1.AD12 (DAC0/CANRX1), R16.1
IO107: J1.AD13 (DAC1), R19.1
IO111: J1.14 (TXD0/14), R24.1
IO112: J1.15 (RXD0/15), R27.1
IO113: J1.30 (PIN30), R30.1
IO114: J1.28 (PIN28), R33.1
IO115: J1.26 (PIN26), R36.1
IO116: J1.24 (PIN24), R39.1
IO117: J1.22 (PIN22), R42.1
IRQ: J1.31 (PIN31), U4.14 (SD_IRQ)
LED_Data: J1.53 (CANTX1/IO/PIN53), R50.2
M1_1: J1.5 (PWM5/5), R46.2, U2.6 (IA)
M1_2: J1.4 (SS1/PWM4/SD-CS/4), R48.1, U2.7 (IB)
M2_1: J1.3 (PWM3/3), R47.2, U3.6 (IA)
M2_2: J1.2 (PWM2/2), R49.1, U3.7 (IB)
MISO: J1.SP1 (MISO), P41.2, P44.2, U4.9 (MISO), U4.13 (SD_MISO)
MOSI: J1.SP4 (MOSI), P41.3, P44.3, U4.6 (MOSI), U4.12 (SD_MOSI)
unnamed: C1.1, D1.2 (K), L1.1, U1.3 (EN), U1.6 (VIN)
unnamed: D1.1 (A), P9.2
unnamed: D2.2 (K), R3.1
unnamed: D3.2 (K), R6.1
unnamed: D4.2 (K), R9.1
unnamed: D5.2 (K), R12.1
unnamed: D6.2 (K), R15.1
unnamed: D7.2 (K), R18.1
unnamed: D8.2 (K), R21.1
unnamed: D9.2 (K), R26.1
unnamed: D10.2 (K), R29.1
unnamed: D11.2 (K), R32.1
unnamed: D12.2 (K), R35.1
unnamed: D13.2 (K), R38.1
unnamed: D14.2 (K), R41.1
unnamed: D15.2 (K), R44.1
unnamed: D16.1 (A), R46.1
unnamed: D17.1 (A), R47.1
unnamed: D18.1 (A), R48.2
unnamed: D19.1 (A), R49.2
unnamed: D20.2 (Dout), D21.4 (Din)
unnamed: D20.4 (Din), R50.1
unnamed: D21.2 (Dout), R51.2
unnamed: L1.2, U1.1 (SW)
unnamed: P1.2, P9.1
unnamed: P2.2, P10.1, Q1.G, R2.2
unnamed: P10.2, R1.2
unnamed: P3.2, P11.1, Q2.G, R5.2
unnamed: P11.2, R4.2
unnamed: P4.2, P12.1, Q3.G, R8.2
unnamed: P12.2, R7.2
unnamed: P5.2, P13.1, Q4.G, R11.2
unnamed: P13.2, R10.2
unnamed: P6.2, P14.1, Q5.G, R14.2
unnamed: P14.2, R13.2
unnamed: P7.2, P15.1, Q6.G, R17.2
unnamed: P15.2, R16.2
unnamed: P8.2, P16.1, Q7.G, R20.2
unnamed: P16.2, R19.2
unnamed: P17.2, P24.1, Q8.G, R25.2
unnamed: P18.2, P25.1, Q9.G, R28.2
unnamed: P19.2, P26.1, Q10.G, R31.2
unnamed: P20.2, P27.1, Q11.G, R34.2
unnamed: P21.2, P28.1, Q12.G, R37.2
unnamed: P22.2, P29.1, Q13.G, R40.2
unnamed: P23.2, P30.1, Q14.G, R43.2
unnamed: P24.2, R24.2
unnamed: P25.2, R27.2
unnamed: P26.2, R30.2
unnamed: P27.2, R33.2
unnamed: P28.2, R36.2
unnamed: P29.2, R39.2
unnamed: P30.2, R42.2
unnamed: P31.2, P33.1, U2.4 (OB)
unnamed: P31.3, P33.2, U2.1 (OA)
unnamed: P32.2, P34.1, U3.4 (OB)
unnamed: P32.3, P34.2, U3.1 (OA)
unnamed: P36.2, U5.2 (RxD)
unnamed: P37.2, U5.3 (TxD)
unnamed: P40.2 (PM), R51.1
unnamed: Q1.D, R3.2
unnamed: Q2.D, R6.2
unnamed: Q3.D, R9.2
unnamed: Q4.D, R12.2
unnamed: Q5.D, R15.2
unnamed: Q6.D, R18.2
unnamed: Q7.D, R21.2
unnamed: Q8.D, R26.2
unnamed: Q9.D, R29.2
unnamed: Q10.D, R32.2
unnamed: Q11.D, R35.2
unnamed: Q12.D, R38.2
unnamed: Q13.D, R41.2
unnamed: Q14.D, R44.2
unnamed: R22.2, R23.2, U1.4 (VFB)
Rx0: J1.0 (RX/URXD/0), P37.1
Rx1: J1.17 (RXD1/17), P37.3
Rx2: J1.19 (RXD2/19), P42.1
SCK: J1.SP3 (SCK), P41.1, P44.1, U4.7 (SCK), U4.10 (SD_SCK)
SCL: J1.SCL (SCL1/TWCK0), P35.1, P38.1, P39.1, R56.2
SDA: J1.SDA (SDA1/TWD0), P35.2, P38.2, P39.2, R55.2
SW: E1.4 (E), J1.27 (PIN27), R54.2
Tx0: J1.1 (TX/UTXD/1), P36.1
Tx1: J1.16 (TXD1/16), P36.3
Tx2: J1.18 (TXD2/18), P42.2
VDD: D2.1 (A), D3.1 (A), D4.1 (A), D5.1 (A), D6.1 (A), D7.1 (A), D8.1 (A), D9.1 (A), D10.1 (A), D11.1 (A), D12.1 (A), D13.1 (A), D14.1 (A), D15.1 (A), J1.IO_R (IOREF), P2.3, P3.3, P4.3, P5.3, P6.3, P7.3, P8.3, P10.3, P11.3, P12.3, P13.3, P14.3, P15.3, P16.3, P17.3, P18.3, P19.3, P20.3, P21.3, P22.3, P23.3, P24.3, P25.3, P26.3, P27.3, P28.3, P29.3, P30.3, P35.3, P38.3, P39.3, P42.3, P43.3, R45.1, R52.1, R53.1, R54.1, R55.1, R56.1
Vm: C2.1, C3.1, C4.1, C5.1, C6.2, D20.1 (Vdd), D21.1 (Vdd), J1.5V, P33.3, P34.3, P40.3, R23.1, U1.5 (VOUT), U2.2 (VCC), U2.3 (VCC), U3.2 (VCC), U3.3 (VCC)

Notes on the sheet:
Bluetooth Radio Interface
Addressable RGB LED
H-Bridge for DC motor
I2C 3
Rotary Encoder and Push
Extension connectors
I2C 2
I2C 1
2.8" LCD Touch Screen ATTENTION 3.3V only Use with Arduino Due
Inputs and Outputs
Arduino Due
AUTODUINO V4
Arduino Due pour le collège
Step Up Switching Power Supply 3v to 5V input 5V output
Extension SPI
Inputs
Outputs
Extension Serial
CAN

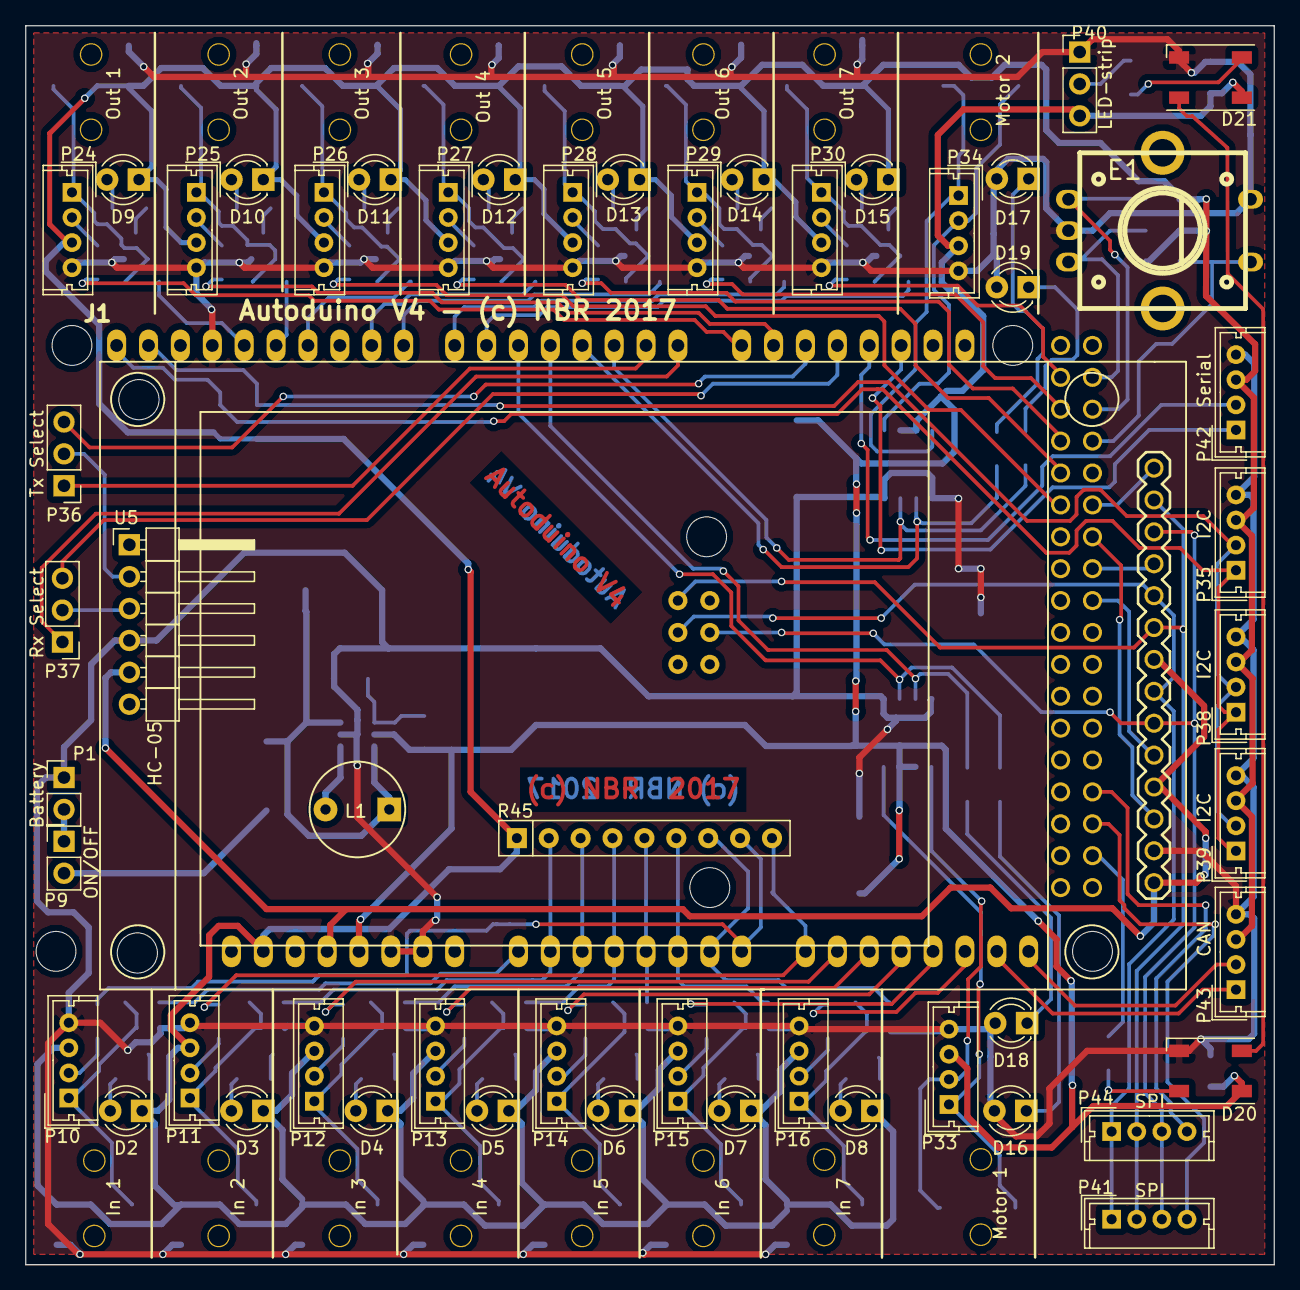
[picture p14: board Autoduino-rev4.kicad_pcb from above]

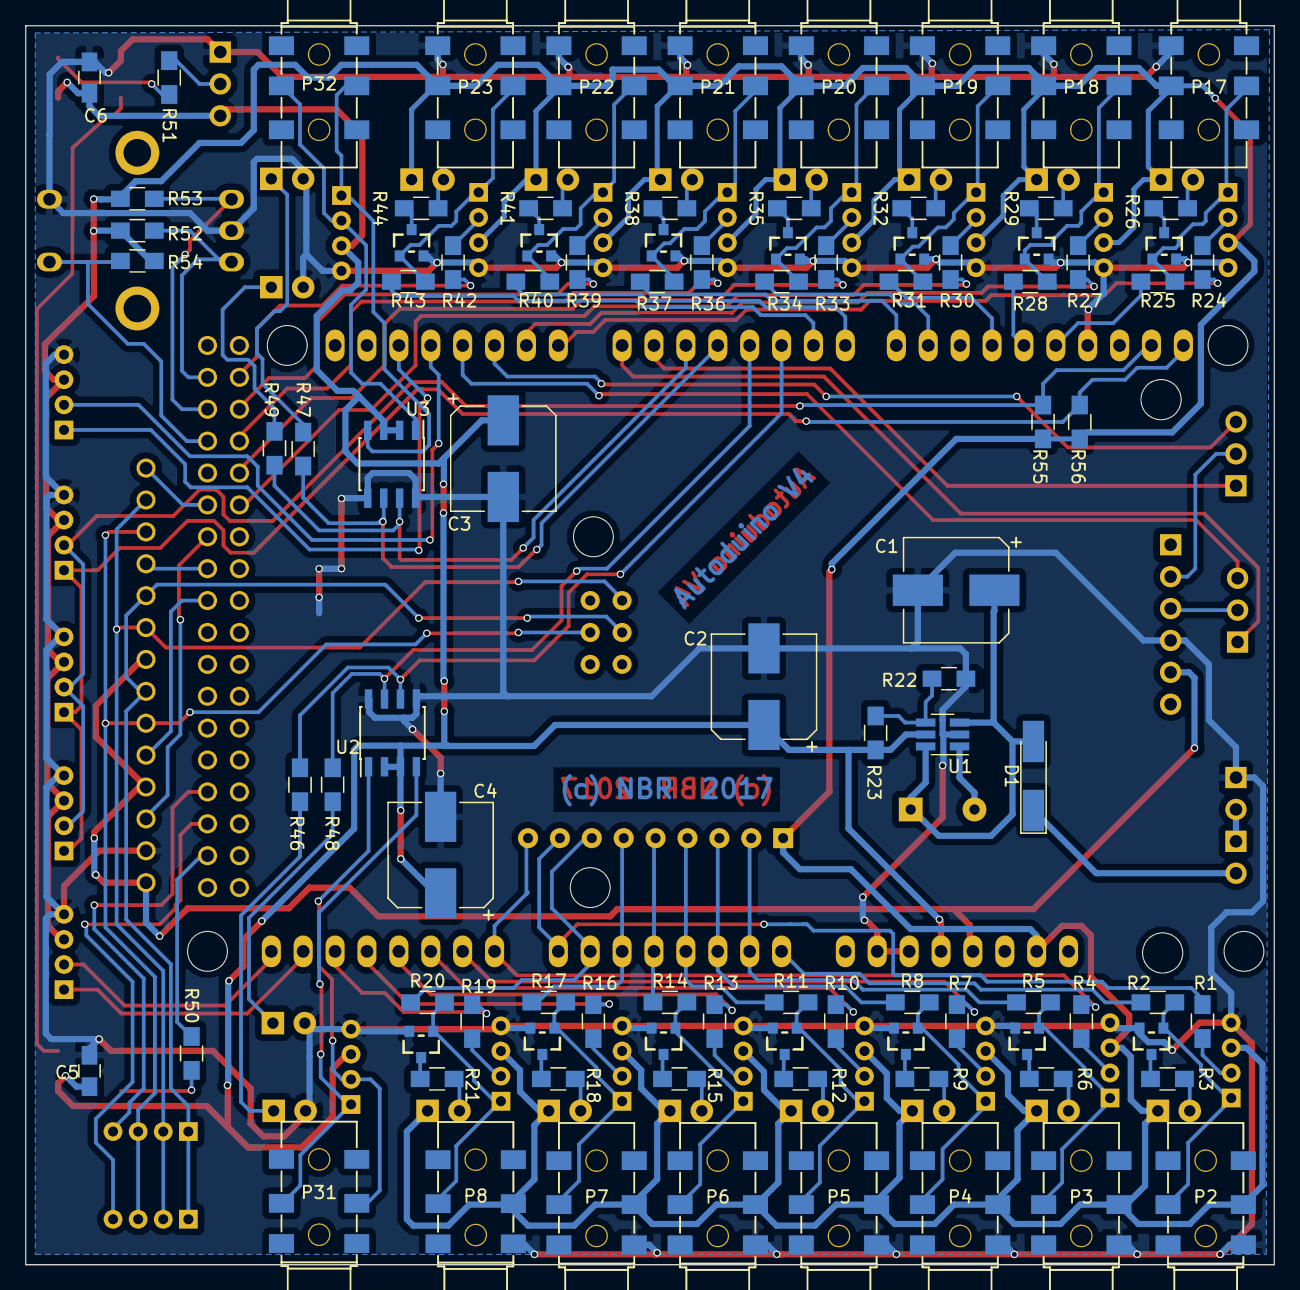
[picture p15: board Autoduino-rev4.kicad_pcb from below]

Board: 2 copper layers, 99.4 x 98.7 mm, 149 parts (95 on the bottom side), 134 nets.

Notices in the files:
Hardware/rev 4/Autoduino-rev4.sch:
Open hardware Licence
